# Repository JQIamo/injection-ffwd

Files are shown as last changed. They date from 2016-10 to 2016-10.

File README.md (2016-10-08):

# Injection FFWD

Based on this paper: [Active stabilization of a diode laser injection lock](http://dx.doi.org/10.1063/1.4953589)
arXiv version: https://arxiv.org/abs/1602.03504

Basic idea: measure the laser peak height on a fabry perot cavity and feed forward to the injection current to maximize the peak height (ie, maintain it in a stable injection locked region)

Implements a crude servo algorithm with auto-relock feature.

Todo:

* status of lock to computer control (pause cycle if in auto-relock)
* ...?

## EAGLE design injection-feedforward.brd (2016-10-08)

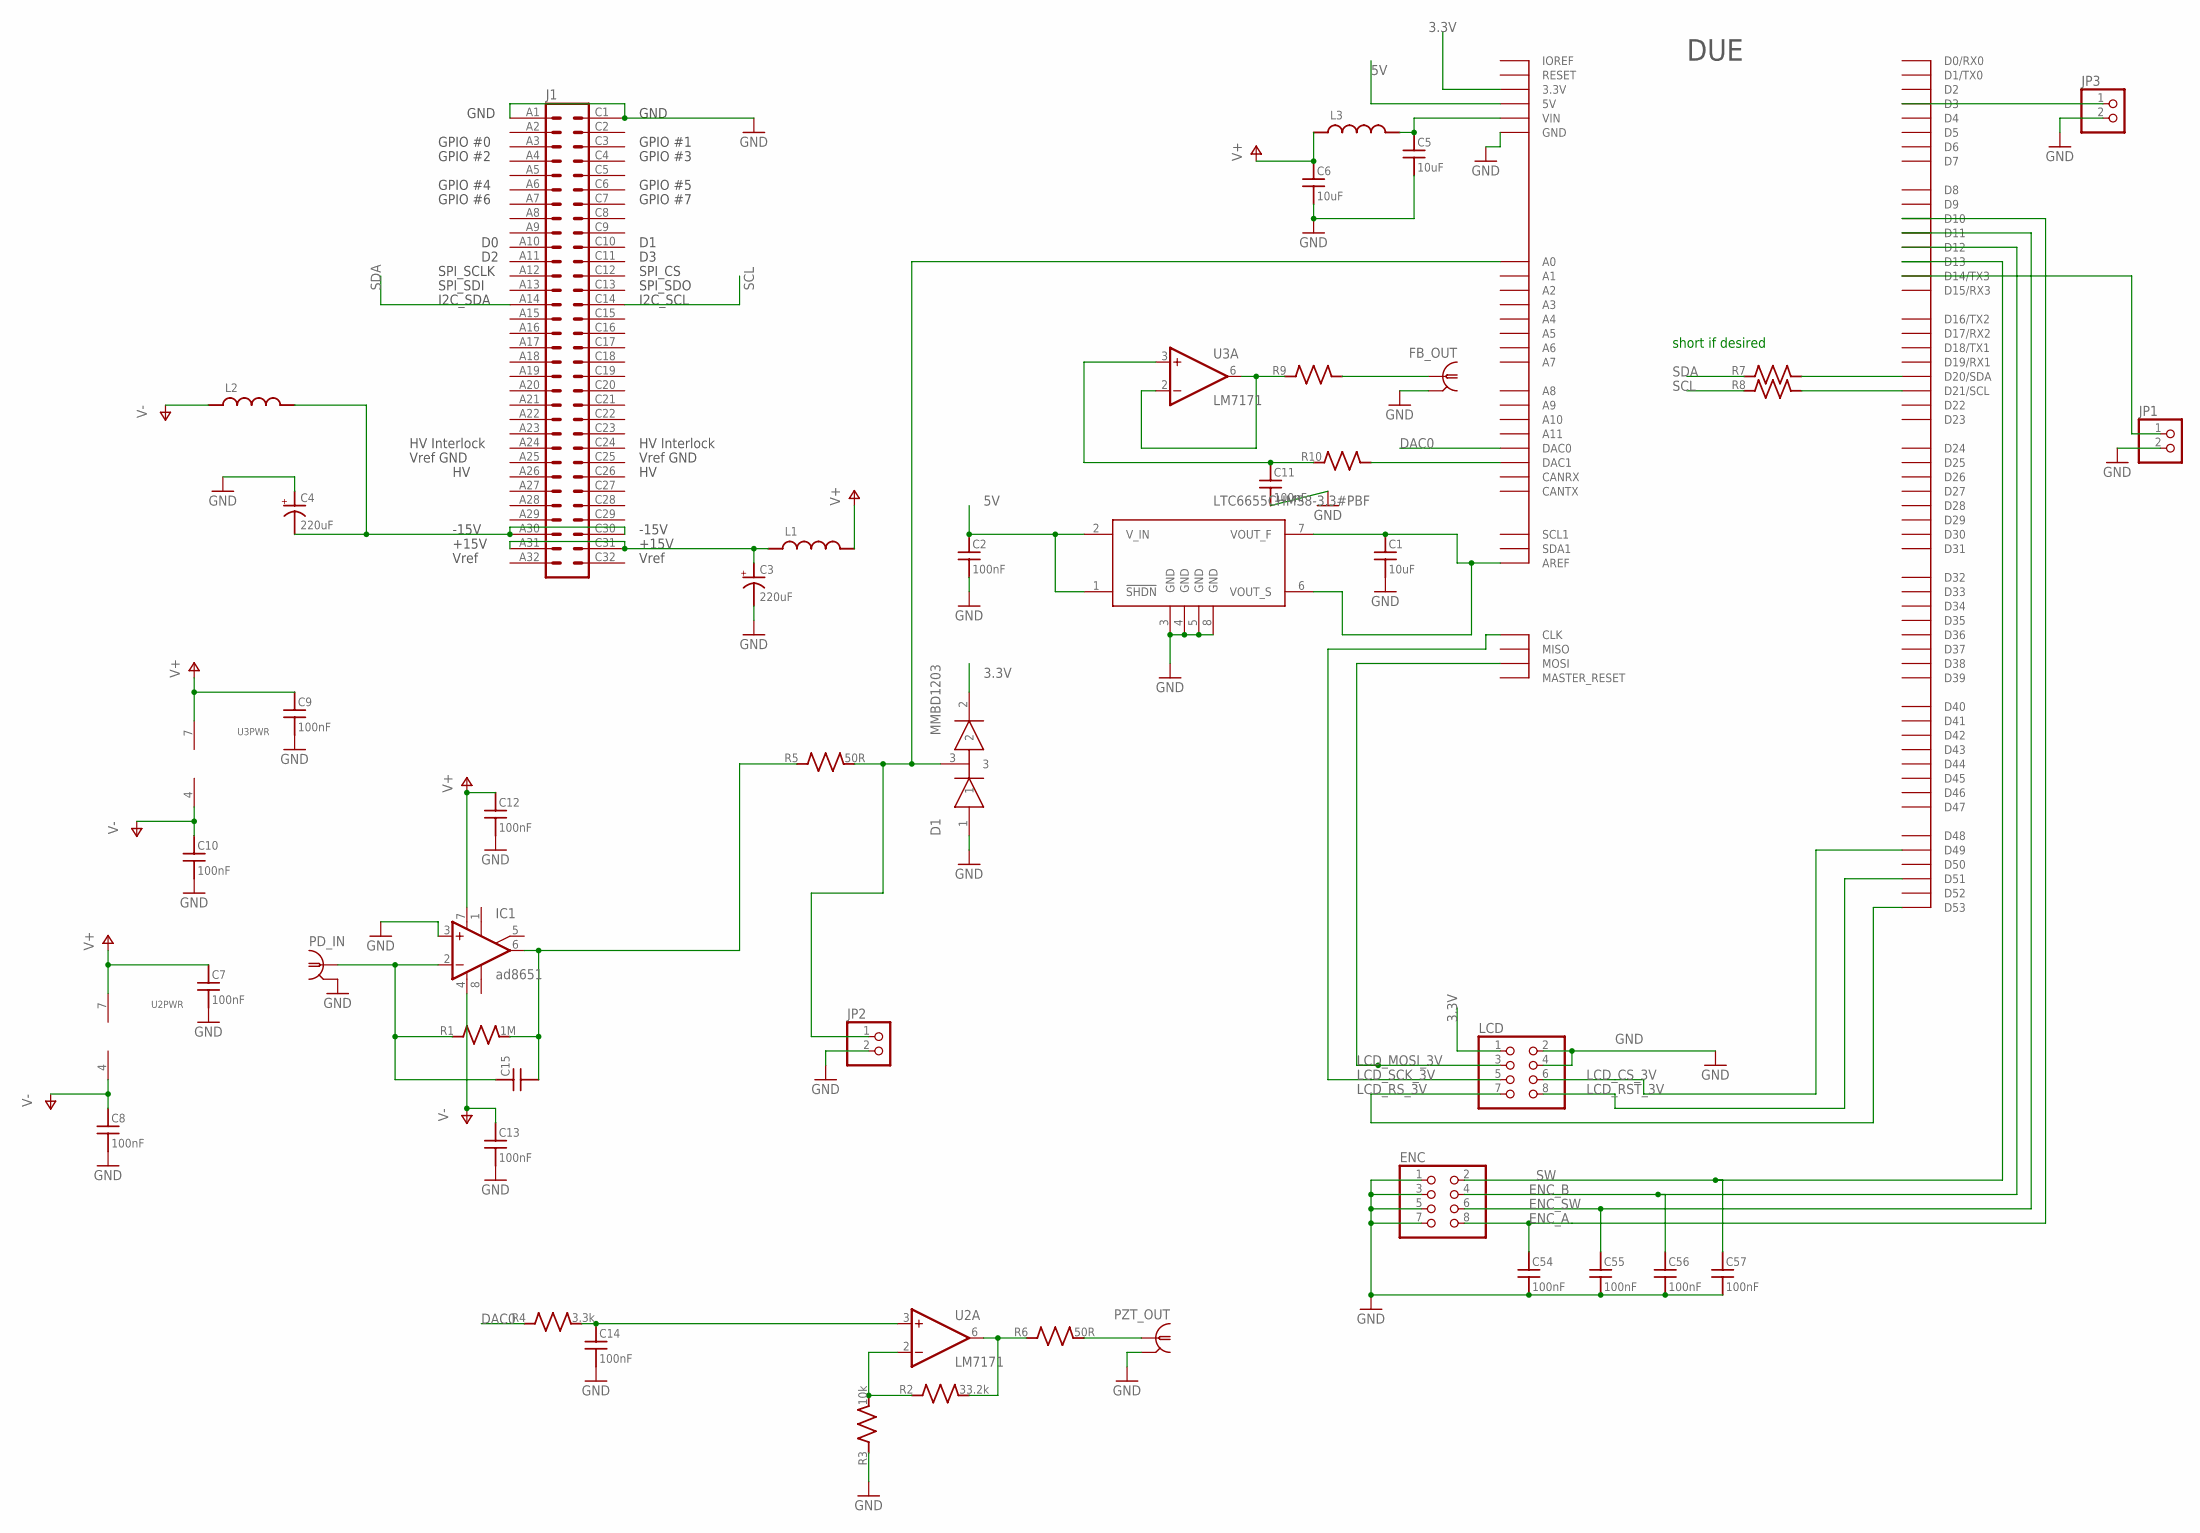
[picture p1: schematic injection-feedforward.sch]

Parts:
C1, C5, C6: 10uF; C_MLCC_0805
C2, C7, C8, C9, C10, C11, C12, C13, C14: 100nF; C_MLCC_0603
C3, C4: 220uF; PANASONIC_F
C15: C_MLCC_SMDCMLCC_0603; C_MLCC_0603
C54, C55, C56, C57: 100nF; C_MLCC_0603; PARTNO 1276-1936-1-ND
D1: MMBD1203; SOT23
ENC: PINHD-2X4-SHROUD; ML08; PARTNO 609-3530-ND
FB_OUT: BNC-H; BNC90
IC1: ad8651; SO08
J1: VG64C; VG64-CUTOUT
JP1, JP2, JP3: PINHD-1X2; 1X02
L1, L2, L3: L_FERRITE_SMDLFERRITE_0603; L_FERRITE_0603
LCD: PINHD-2X4-SHROUD; ML08; PARTNO 609-3530-ND
PD_IN: BNC-H; BNC90
PZT_OUT: BNC-H; BNC90
R1: 1M; R_0603
R2: 33.2k; R_0603
R3: 10k; R_0603
R4: 3.3k; R_0603
R5, R6: 50R; R_0603
R7, R8, R9, R10: R_SMDR0603; R_0603
U1: LTC6655CHMS8-3.3#PBF; MSOP8
U2, U3: LM7171; SO08$1
U$1: DUE_SHIELD

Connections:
3.3V: D1.2, LCD.1, U$1.3.3 (3.3V)
5V: C2.P$1 (1), U1.1 (!SHDN), U1.2 (V_IN), U$1.5V0 (5V), U$1.5V1 (5V), U$1.5V2 (5V), U$1.5V3 (5V)
DAC0: R4.P$1 (1), U$1.DAC0
ENC_A: C54.P$1 (1), ENC.8, U$1.10 (D10)
ENC_B: C56.P$1 (1), ENC.4, U$1.12 (D12)
ENC_SW: C55.P$1 (1), ENC.6, U$1.11 (D11)
GND: C1.P$2 (2), C2.P$2 (2), C3.-, C4.+, C5.P$2 (2), C6.P$2 (2), C7.P$2 (2), C8.P$2 (2), C9.P$2 (2), C10.P$2 (2), C11.P$2 (2), C12.P$2 (2), C13.P$2 (2), C14.P$2 (2), C54.P$2 (2), C55.P$2 (2), C56.P$2 (2), C57.P$2 (2), D1.1, ENC.1, ENC.3, ENC.5, ENC.7, FB_OUT.2, IC1.3 (+IN), J1.A1, J1.C1, JP1.2, JP2.2, JP3.2, LCD.2, LCD.4, PD_IN.2, PZT_OUT.2, R3.P$1 (1), U1.3 (GND), U1.4 (GND), U1.5 (GND), U1.8 (GND), U$1.GND, U$1.GND0 (GND), U$1.GND1 (GND), U$1.GND2 (GND), U$1.GND3 (GND), U$1.GND4 (GND)
LCD_CS_3V: LCD.6, U$1.49 (D49)
LCD_MOSI_3V: LCD.3, U$1.MOSI
LCD_RST_3V: LCD.8, U$1.51 (D51)
LCD_RS_3V: LCD.7, U$1.53 (D53)
LCD_SCK_3V: LCD.5, U$1.CLK
unnamed: C1.P$1 (1), U1.6 (VOUT_S), U1.7 (VOUT_F), U$1.AREF
unnamed: C3.+, J1.A31, J1.C31, L1.P$1 (1)
unnamed: C4.-, J1.A30, J1.C30, L2.P$2 (2)
unnamed: R7.P$2 (2), U$1.20 (D20/SDA)
unnamed: R9.P$1 (1), U3.2 (-IN), U3.6 (OUT)
unnamed: C5.P$1 (1), L3.P$2 (2), U$1.VIN
unnamed: R2.P$1 (1), R3.P$2 (2), U2.2 (-IN)
unnamed: R2.P$2 (2), R6.P$1 (1), U2.6 (OUT)
unnamed: C15.P$1 (1), IC1.2 (-IN), PD_IN.1, R1.P$1 (1)
unnamed: C15.P$2 (2), IC1.6 (OUT), R1.P$2 (2), R5.P$1 (1)
unnamed: C14.P$1 (1), R4.P$2 (2), U2.3 (+IN)
unnamed: JP1.1, U$1.14 (D14/TX3)
unnamed: D1.3, JP2.1, R5.P$2 (2), U$1.A0
unnamed: PZT_OUT.1, R6.P$2 (2)
unnamed: R8.P$2 (2), U$1.21 (D21/SCL)
unnamed: FB_OUT.1, R9.P$2 (2)
unnamed: C11.P$1 (1), R10.P$1 (1), U3.3 (+IN)
unnamed: R10.P$2 (2), U$1.DAC1
unnamed: JP3.1, U$1.3 (D3)
SCL: J1.C14, R8.P$1 (1)
SDA: J1.A14, R7.P$1 (1)
SW: C57.P$1 (1), ENC.2, U$1.13 (D13)
V+: C6.P$1 (1), C7.P$1 (1), C9.P$1 (1), C12.P$1 (1), IC1.7 (V+), L1.P$2 (2), L3.P$1 (1), U2.7 (V+), U3.7 (V+)
V-: C8.P$1 (1), C10.P$1 (1), C13.P$1 (1), IC1.4 (V-), L2.P$1 (1), U2.4 (V-), U3.4 (V-)

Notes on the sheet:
short if desired

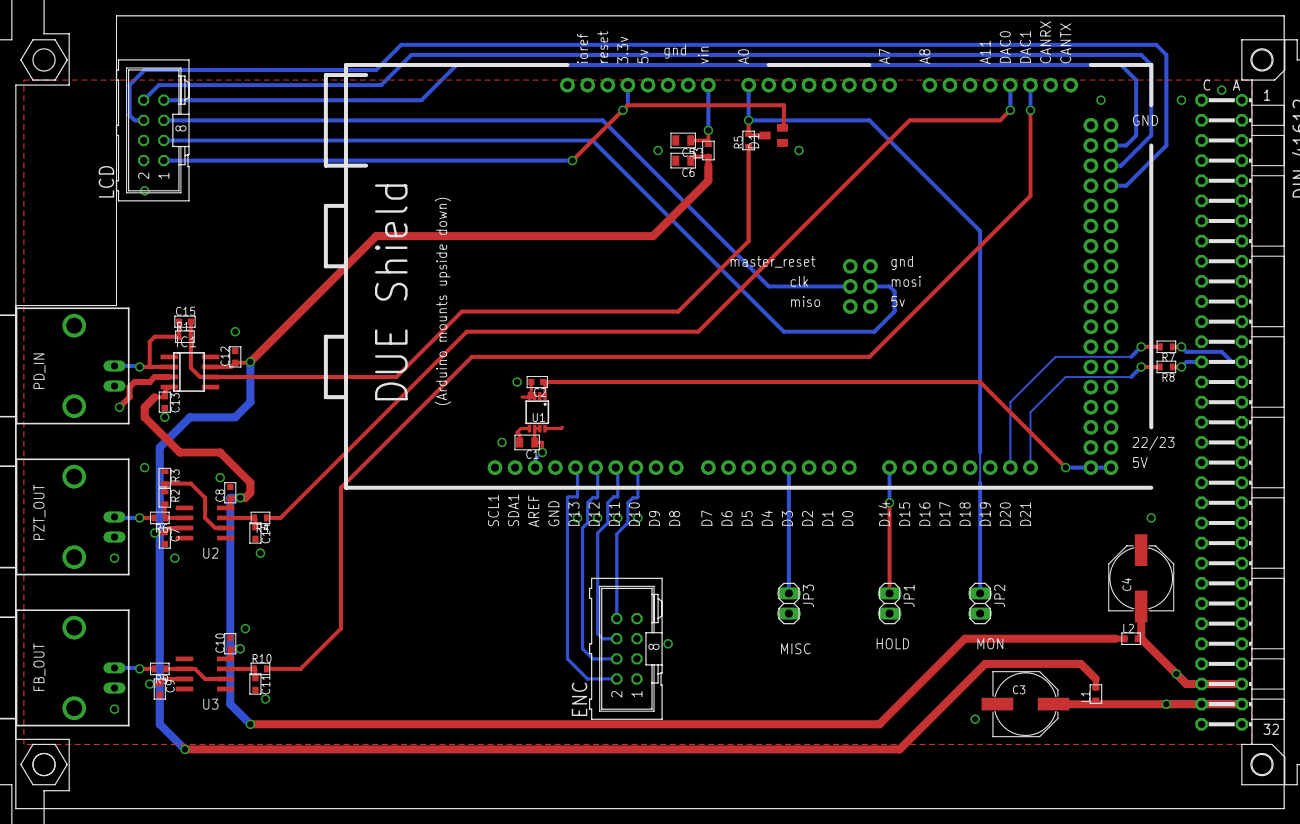
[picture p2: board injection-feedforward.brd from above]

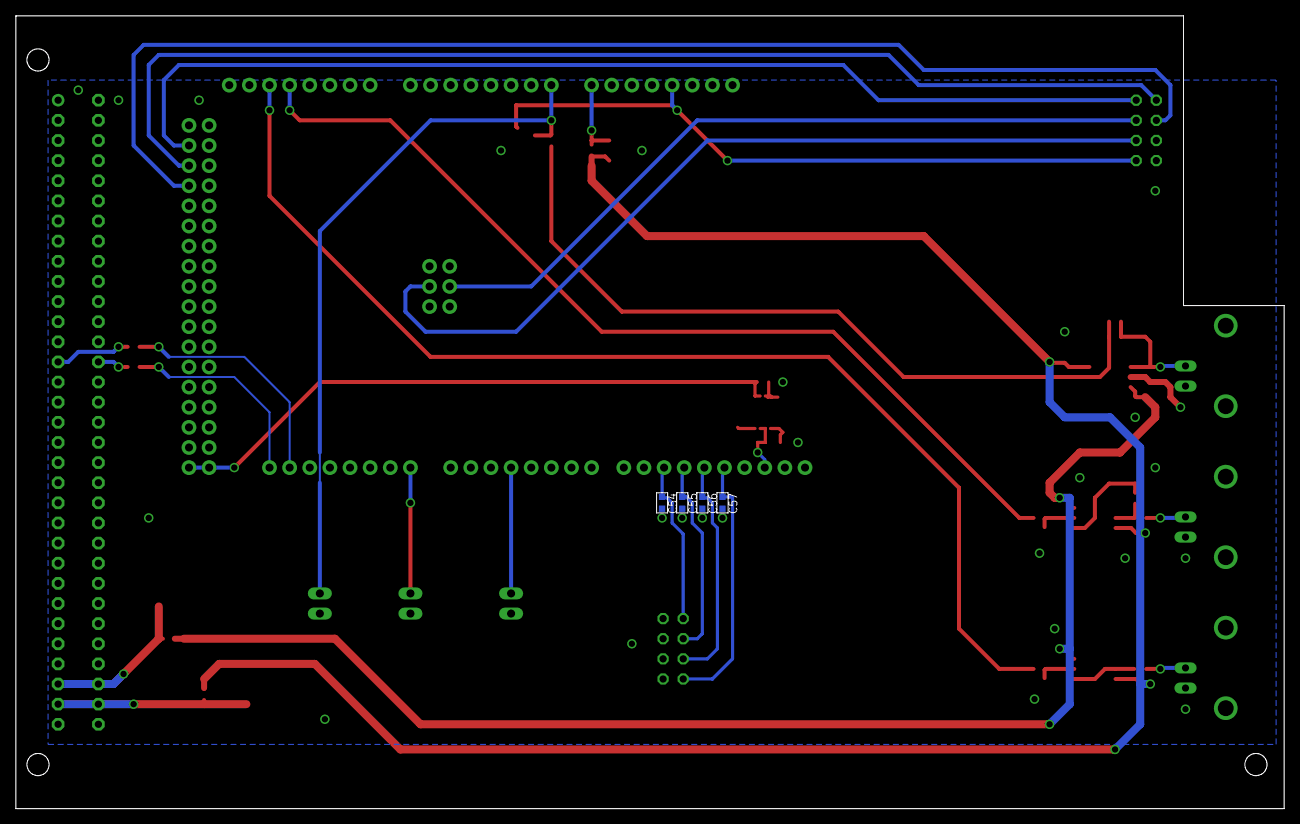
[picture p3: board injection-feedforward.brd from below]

Board: 2 copper layers, 160.0 x 100.0 mm, 47 parts (4 on the bottom side), 36 nets.

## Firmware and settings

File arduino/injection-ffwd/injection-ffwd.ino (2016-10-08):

#include "DueTimer/DueTimer.h"
#include "injection-init.h"

/*

// states
r[0]: Reset state; DAC -> midscale; piezo scan is on but no FB
l[1]: lock state; implements PID
a[2]: acquire; implements re-acquire routine

// parameters
p -> interpret as parameter
command structure: 'p 0 15' -> set param 0 (pzt_min) to 15

0 pzt_min
1 pzt_max
2 scans_to_average
3 reaq_stepsize
4 fb_stepsize
5 unlocked_threshold
6 locked_threshold
7 pzt_offset_delta
*/

//DueTimer timer(0);

volatile bool ramp_dir = 1; // 1 = rising; 0 = falling
volatile bool end_scan_flag = 0;    // flag for end of single period of pzt scan

uint16_t fb_o = 2048;   // current feedback output; set to mid-scale.


int unlocked_threshold = 1250;
int locked_threshold = 1450;
int fb_stepsize = 30;
int reaq_stepsize = 250;

int pzt_offset_delta = 300;


// state for state machine
int state = 0;
bool railed = 0;


int scan_counter = 0;
float average_height = 0.0;
float global_average = 0.0;


//lockmode_t fb_mode;

int fb_flag = 0;


uint16_t df_fb = 300;

int lock_sm = 0;
float lock_hist[3];
uint16_t lock_val[3];






// generate triangle ramp 
void advance_waveform(){
  pzt_o += (ramp_dir ? PZT_RRR : PZT_FRR);

  // check bounds, correct if necessary and reverse ramp direction.
  if (pzt_o >= pzt_max){
    pzt_o = pzt_max;
    ramp_dir = 0;
  } else if (pzt_o < pzt_min){
    pzt_o = pzt_min;
    ramp_dir = 1;

    Timer1.stop();
    NVIC_DisableIRQ(ADC_IRQn);
    end_scan_flag = 1;
  }

  analogWrite(DAC0, pzt_o);
}

void reset_waveform(){
  pzt_o = pzt_min;
  ramp_dir = 1;
  end_scan_flag = 0;
  pk_count = 0;
}



void query_cavity(){
  reset_waveform(); // reset counters, buffers, etc.
  NVIC_EnableIRQ(ADC_IRQn); // turn on ADC interrupts
  Timer1.start();   // timer is attached to advance_waveform; enable to start PZT waveform generation
}


/* State machine:

Sc

*/




void setup() {

  Serial.begin(115200);
  
  adc_dac_setup();  // configure ADC & DAC
  
  // output voltages on PZT and DAC
  analogWrite(DAC0, pzt_min);
  analogWrite(DAC1, fb_o);
  
 // timer = DueTimer(0);

  
  // attach timer interrupt for PZT waveform
  Timer1.attachInterrupt(advance_waveform).setPeriod(PZT_TIMESTEP);
  
  // initialize state machine...?
  state = 0;
  // start
  query_cavity();

}





void update_fb(){

    // make sure we loop back to 4095
    if (fb_o > 4095){
        fb_o = 4095;
    }


    // if in lock mode and fb_o close to rail, throw rail flag
    // else, loop at 12 bits
    if (state == 1 &&  (((4095 - fb_o) < RAILED_OVERHEAD) || fb_o < RAILED_OVERHEAD)){
        railed = 1;
    } else {
        railed = 0;
    }
    
    analogWrite(DAC1, fb_o);    
}


void processSM(){

   
    switch (state){
    case 0:
        // state 0: reset
        fb_o = 2048;
        update_fb();
        query_cavity();
        break;
    
    case 1:
        // state 1: lock mode
        
        
        break;
        
    case 2:
    
        break;
        
    default:
        fb_o = 2048;
        update_fb();
        query_cavity();
        break;
    }


}

void processSerial(){
 // check for serial
    if (Serial.available() > 0){
        char c = Serial.read();
        switch (c){
        case 'r':
            // reset state
            state = 0;
           //  Serial.print("state: ");
//             Serial.println(state);
            break;
        case 'l':
            // lock state
            state = 1;
//             Serial.print("state: ");
//             Serial.println(state);            
            break;
        case 'a':
            // lock state
            state = 2;
           //  Serial.print("state: ");
//             Serial.println(state);           
            break;
        
        case 'p':
            // 0 pzt_min
            // 1 pzt_max
            // 2 scans_to_average
            // 3 reaq_stepsize
            // 4 fb_stepsize
            // 5 unlocked_threshold
            // 6 locked_threshold
            // 7 pzt_offset_delta
            int pnum = Serial.parseInt();
            int val = Serial.parseInt();
            switch (pnum){
            case 0:
                pzt_min = val;
                break;
            case 1:
                pzt_max = val;
                break;
            case 2:
                scans_to_average = val;
                break;
            case 3:
                reaq_stepsize = val;
                break;
            case 4:
                fb_stepsize = val;
                break;
            case 5:
                unlocked_threshold = val;
                break;
            case 6:
                locked_threshold = val;
                break;
            case 7:
                pzt_offset_delta = val;
                break;
                    
            
            
            }
        }
        
        // not sure why flush() is broken...
        // but then again so is this :/
        while (Serial.available() > 0){
            Serial.read();
        }
        processSM();
    }
}


float process_scan(){

// increment scan count
      scan_counter++;
      
      uint16_t peak_heights[MAX_PEAK_CT];
      uint8_t pk_height_idx = 0;
      
      uint16_t current_max;
      
      // stash peak maxima
      for (int i = 0; i < pk_count; i++){
        current_max = 0;
        for (int j = 0; j < pt_count[i]; j++){
            current_max = (buf[i][j] > current_max) ? buf[i][j] : current_max;
        }
        peak_heights[pk_height_idx++] = current_max;
      }
      
      // calculate average
      uint32_t sum = 0;
      for (int i = 0; i < pk_height_idx; i++){
        sum += peak_heights[i];
      }
      
      // adjust pzt_min in case too close to turnaround.
      // want to servo first peak at pzt_min + 300??
      
//       if (pk_count > 1){
//           int pzt_offset = pk_position[0] - pzt_offset_delta;
//           if (pzt_offset < 0){
//             pzt_min = pk_position[0] + pzt_offset_delta;
//           } else {
//             pzt_min = pzt_offset;
//           }
//       }
      return ((float) sum / pk_count);
    
}


float old_average = 0.0;
int polarity = 1;

void loop() {

    processSerial();
   
    
    // if finished a scan, calculate average peak height
    if (end_scan_flag){
        // reset scan flag
        end_scan_flag = 0;
       // reject scans with bad peak count?
        average_height +=  process_scan();
        
        if (scan_counter % scans_to_average == 0){
            global_average = average_height/scans_to_average;
            
            if (isnan(global_average) && state != 0){
                state = 2;        
            }
            
            Serial.print(global_average);
            Serial.print("\t");
            Serial.print(fb_o);
            Serial.print("\t");
            Serial.print(state);
            Serial.print("\t");
            Serial.println(polarity);
            
            switch (state){
            case 0:
                // reset mode
                break;
            case 1:
                // lock mode
                if (unlocked_threshold < global_average && global_average <= locked_threshold){
                    // if "locked" but marginal, step current to see which side
                    old_average = global_average;
                    fb_o += fb_stepsize*polarity;
                    state = 11;
                
                    update_fb();
                   
                } else if(global_average < unlocked_threshold){
                    state = 2;  // put in re-acquire mode
                }
                //otherwise, do nothing!
                break;
            
            case 11:
                // entered here from lock mode; sampling which side of lock region
                if (global_average < old_average){
                    // moving in wrong direction, flip polarity
                    polarity = -1*polarity;
                }
                fb_o += fb_stepsize*polarity;
                old_average = global_average;
            
            
                if (global_average > locked_threshold){
                    fb_o += fb_stepsize*polarity;
                    state = 1;
                } else if (global_average < unlocked_threshold){
                    // messed up, try to reacquire lock
                    state = 2;
                }
                update_fb();
                break;
            
            case 2:
                // need to re-acquire
                if (global_average > unlocked_threshold){
                    // lock has caught, so go into locking mode!
                    state = 1;
                } else {
                    fb_o -= reaq_stepsize;
                    update_fb();
                }
                break;
            
            
        
        
            }
        
            // reset average height
            average_height = 0.0;
        }
        
        delay(1);
        query_cavity();
    } 
}  


       //  if (fb_flag == 1){
//             if (average_height/scans_to_average >= 1450.0){ 
//                 fb_flag = 2; // move to locked mode
//                 Serial.print("Lock mode\t");
//                 Serial.println(fb_o);
//             } else {
//                   Serial.print(fb_o);
//             Serial.print("\t");
//             Serial.println(global_ave);
//                 fb_o -= df_fb;
//                 analogWrite(DAC1, fb_o);
//             }
//         } else if (fb_flag == 2){
//             // if in locked mode...
//             switch (lock_sm){
//             
//                 case 0:
// 
//                 lock_hist[0] = global_ave;
//                 lock_val[0] = fb_o;
//                 
//                 // only do something if at edge of range
//                 if(lock_hist[0] < 1450 || isnan(lock_hist[0])){
//                                   
//                 
//                 // sample up next time around
//                 fb_o += 30;
//                 analogWrite(DAC1, fb_o);
//                 lock_sm = 1;
//                 }
//                 break;
//                 
//                 case 1:
//        
// 
//                 lock_hist[1] = global_ave;
//                 lock_val[1] = fb_o;
//                 // sample down next time around
//                 fb_o = lock_val[0] - 30;
//                 analogWrite(DAC1, fb_o);
//                 
//                 lock_sm = 2;
//                 break;
//                 
//                 case 2:
//       
//                 lock_hist[2] = global_ave;
//                 lock_val[2] = fb_o;
//       
//                 Serial.print("lock\t");
//                 Serial.print(fb_o+30);
//                 Serial.print("\t");
//                 Serial.print(lock_hist[2]);
//                 Serial.print("\t");
//                 Serial.print(lock_hist[0]);
//                 Serial.print("\t");
//                 Serial.println(lock_hist[1]);
//               
//                 
//       
//                 if(lock_hist[2] > (lock_hist[0]+5)){
//                     Serial.println("decreasing");
//                     //fb_o = lock_val[2];
//                     fb_o = lock_val[0] - 60;
//                 //fb_o -= 2*30;
//                 analogWrite(DAC1, fb_o);
//                 } else if (lock_hist[1] > (lock_hist[0] + 5)){
//                     //fb_o = lock_val[1]; 
//                     fb_o = lock_val[0] + 60;
//                     analogWrite(DAC1, fb_o);
//                     
//                     Serial.println("increasing");
//                     }else if (isnan(lock_hist[0])){
//                         lock_sm = 0;
//                
//                         fb_flag = 1;
//                         df_fb = 300;
//                         fb_o = 4000;
//                         Serial.println("relocking");
//                     }
//                     else {
//                     fb_o = lock_val[0];
//                     analogWrite(DAC1, fb_o);
//                     //Serial.println("same");
//                     } 
//                 lock_sm = 0;
//                 break;
//                 
//                 
//             }
//         }
//         average_height = 0.0;
//       }

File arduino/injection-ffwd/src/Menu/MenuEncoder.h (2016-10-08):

#ifndef MENUENCODER_H
#define MENUENCODER_H

#include "Arduino.h"
//#include "digitalWriteFast.h"

#define ENC_SW 21
#define ENC_A 22
#define ENC_B 23

#define HOLD_TIMEOUT 300
#define PUSH_TIMEOUT 50
#define CHEAT_CODE "PP-+-+PP"
#define CHEAT_LEN 8

struct Encoder {
  volatile int16_t pos = 0;
  volatile bool flag = 0;
  volatile unsigned long millis_down = 0;
  volatile unsigned long millis_up = 0;
} LCDENC;


void pollEncoder(){
  digitalReadFast(ENC_B) ? LCDENC.pos++ : LCDENC.pos--;
}

void pollEncoderSW(){
  if(digitalReadFast(ENC_SW)){
    LCDENC.millis_up = millis();
    LCDENC.flag = 1;
  } else {
    LCDENC.millis_down = millis();
    LCDENC.flag = 0;
  }

}

// void pollEncoderSW2(){
//   LCDENC.millis_up = millis();
//   LCDENC.flag = 1;
// }

class EncoderStream : public Stream {
public:

EncoderStream(Encoder & enc) : enc(enc){};

  Encoder & enc;
  int oldPos;

  void begin(){
    _cheat_idx = CHEAT_LEN;
    strcpy(_cheat_code, CHEAT_CODE);

    pinMode(ENC_A, INPUT_PULLUP);
    pinMode(ENC_B, INPUT_PULLUP);
    pinMode(ENC_SW, INPUT_PULLUP);

    attachInterrupt(ENC_A, pollEncoder, FALLING);
    attachInterrupt(ENC_SW, pollEncoderSW, CHANGE);
  //  attachInterrupt(ENC_SW, pollEncoderSW2, RISING);
    // // set up interrupts for both INT0, 1 only...
    // //EICRA = _BV(3);
    // EICRA = 0x07; // binary 0b0110; INT0 on falling edge, INT1 on change
    // EIMSK = 0x03;
  }

  int available() {
      return (enc.pos != oldPos || enc.flag);
  }

  int peek() {
    if (enc.pos < oldPos) return '-';
    if (enc.pos > oldPos) return '+';
    if (enc.flag) {
      if ((enc.millis_up - enc.millis_down) > HOLD_TIMEOUT) return 'H';
      if ((enc.millis_up - enc.millis_down) > PUSH_TIMEOUT) return 'P';
    }
     // what about hold?
    // need to fix this!! FIX
    //if (_push_action || (PIND & _BV(6))) return _push_action;
    return -1;
  }

  int read() {
    if (!strcmp(_cheat, _cheat_code)){
      Serial.println("cheat activated!!");
      Serial.println(_cheat);
      flush_buffer();
      return 'C';
    }
    if (enc.pos < oldPos) {
      //oldPos = _buff_en ? oldPos + 1 : enc.pos;
      oldPos = enc.pos;
      //_cheat[_cheat_idx++ % CHEAT_LEN] = '-';
      cheat_buffer('-');
      Serial.println(_cheat);
      return '-';
    }
    if (enc.pos > oldPos) {
      //oldPos = _buff_en ? oldPos + 1 : enc.pos;
      oldPos = enc.pos;
      //_cheat[_cheat_idx++ % CHEAT_LEN] = '+';
      cheat_buffer('+');
      Serial.println(_cheat);
      return '+';
    }

    if (enc.flag) {
      enc.flag = 0;
      if ((enc.millis_up - enc.millis_down) > HOLD_TIMEOUT) {
        flush_buffer();
        Serial.println(_cheat);
        return 'H';
      }
      if ((enc.millis_up - enc.millis_down) > PUSH_TIMEOUT){
        cheat_buffer('P');
        //_cheat[_cheat_idx++ % CHEAT_LEN] = 'P';
        Serial.println(_cheat);
        return 'P';
      }
    }

    // push button... if encoder not rotating
    //if (!digitalRead(ENC_SW) && ! _sw_pushed){
    // custom... switch on PD6

    // switch state: bit 1 = ~ switch; bit 0 = internal switch state tracker
    // note: because of pullup, switch -> 1 = off, switch -> 0 = on
    //  0 0 -> pushed, wasn't pushed last time = pushed state
    //  0 1 -> pushed, was pushed last time = hold vs push state timeout
    //  1 0 -> not pushed, wasn't pushed last time = nothing
    //  1 1 -> not pushed, was pushed last time = released state
    // bool switch_state = PIND & _BV(6);
    // int state = (switch_state << 1) | _sw_pushed;
    // int curr_millis;
    // Serial.print("State ");
    // Serial.println(state);
    //
    // switch (state){
    //   case 0:
    //     // pushed, wasn't pushed last time; change to pushed state
    //     _sw_pushed = true;
    //     _push_millis = millis();
    //     break;
    //   case 1:
    //     // pushed, was pushed last time; check if holding or pushing
    //     curr_millis = millis();
    //     if (curr_millis - _push_millis > HOLD_TIMEOUT){
    //       _push_action = 'H';
    //     } else if (curr_millis - _push_millis > PUSH_TIMEOUT){
    //       _push_action = 'P';
    //     } else {
    //       _push_action = 0;
    //     }
    //     break;
    //   //case 2:
    //     // not pushed, wasn't pushed last time so do nothing
    //     //break;
    //   case 3:
    //     // not pushed, was pushed last time so release state
    //     int action = _push_action;
    //     _push_action = 0;
    //
    //     return action;
    //     //break;
    // }

    return -1;
  }


  void flush() {
    oldPos = enc.pos;
    enc.flag = 0;
  }

  size_t write(uint8_t val) {
    oldPos = val;
    enc.pos = val;  // update encoder to this position as well...
    return 1;
  }

  void cheat_buffer(char c){
    if (_cheat_idx < CHEAT_LEN){
      _cheat[_cheat_idx++] = c;
      _cheat[_cheat_idx] = '\0';
    }
    Serial.print("index: ");
    Serial.println(_cheat_idx);
    Serial.println(_cheat);
  }

  void flush_buffer(){
    _cheat_idx = 0;
    _cheat[_cheat_idx] = '\0';
  }

private:
  int _a, _b, _sw;
  char _cheat[CHEAT_LEN + 1];
  char _cheat_code[CHEAT_LEN];
  int _cheat_idx;

};


#endif

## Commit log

2016-10-08 Initial board design
    Has some defects:
    * need to power PD op amp at 5V not +/-15V
    [injection-feedforward.brd, injection-feedforward.sch]
2016-10-08 initial code commit; mostly working
    * still need to implement display, rotary encoder
    * eventual integration over backplane?
